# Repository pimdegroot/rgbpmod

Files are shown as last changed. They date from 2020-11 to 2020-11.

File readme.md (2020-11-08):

# RGB Pmod
 ## Introducion
 In this repo you can find the design files and a code example for the rgb matrix pmod I designed. It is based on a 1x1mm RGB led and the GN1640 LED driver.

 The leds used are: https://lcsc.com/product-detail/Light-Emitting-Diodes-LED_Foshan-NationStar-Optoelectronics-FC-B1010RGBT-HG_C158099.html

And the driver is: https://lcsc.com/product-detail/LED-Drivers_GN-GN1640_C265478.html

Note that the TM1640 is pin compatible and an english datasheet can be found for that chip.

When replicating this project it is highly recommended to order a stencil and use solder paste to solder the LEDs

## Usage and Support
Feel free to use the design and code in this repo for your own project. Please credit this repo, or @mifune on twitter if you do.

This is a hobby project that I shared because there has been some interest in it. I will not offer it for sale (though I won't stop you from doing so). Please let me know if there is a file missing in the repo, other than that I won't offer support. I'm already working on the next project.

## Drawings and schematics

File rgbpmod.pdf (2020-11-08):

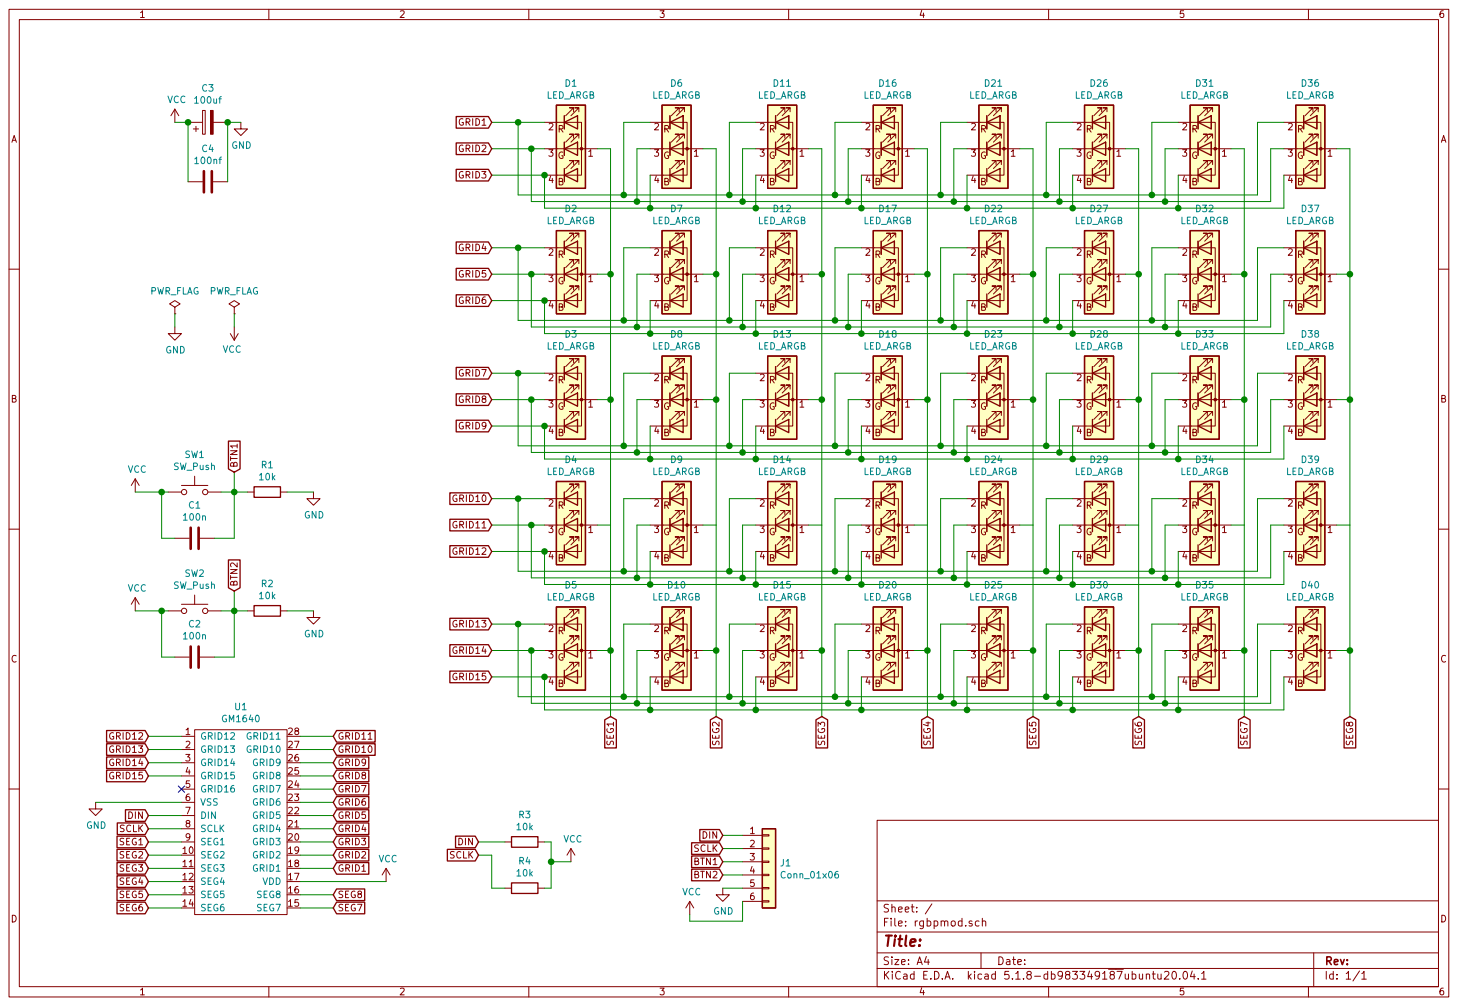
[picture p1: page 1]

File: rgbpmod.sch Sheet: / R4

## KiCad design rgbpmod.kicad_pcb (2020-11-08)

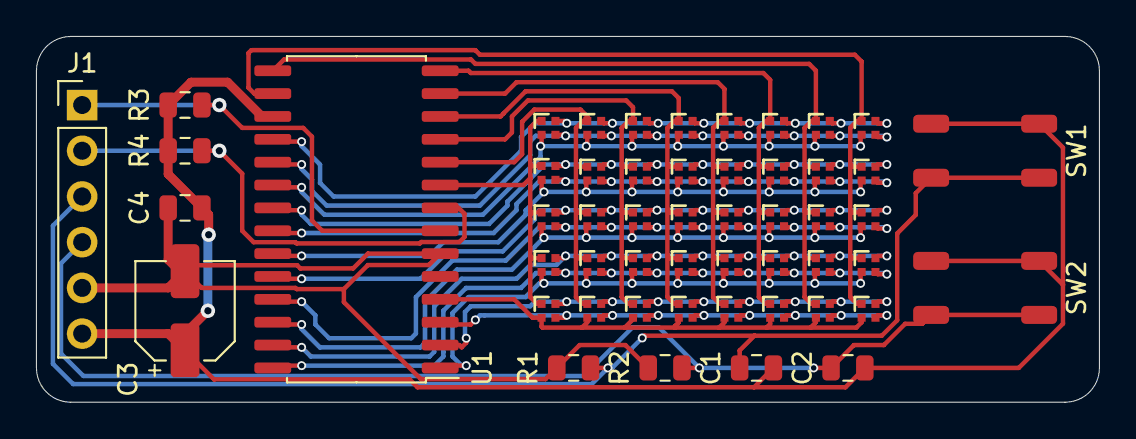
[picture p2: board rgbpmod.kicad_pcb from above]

Board: 2 copper layers, 59.1 x 20.3 mm, 52 parts (0 on the bottom side), 29 nets.

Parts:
C1, C2: 100n; C_0805_2012Metric
C3: 100uf; CP_Elec_5x5.4
C4: 100nf; C_0805_2012Metric
D1, D2, D3, D4, D5, D6, D7, D8, D9, D10, D11, D12, D13, D14, D15, D16, D17, D18, D19, D20, D21, D22, D23, D24, D25, D26, D27, D28, D29, D30, D31, D32, D33, D34, D35, D36, D37, D38, D39, D40: LED_ARGB; 0404_RGB_LED
J1: Conn_01x06; PinHeader_1x06_P2.54mm_Vertical
R1, R2, R3, R4: 10k; R_0805_2012Metric
SW1, SW2: SW_Push; SW
U1: GM1640; SOIC-28W_7.5x17.9mm_P1.27mm

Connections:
BTN1: C1.1, J1.3, R1.2, SW1.2
BTN2: C2.1, J1.4, R2.2, SW2.2
DIN: J1.1, R3.2, U1.7
GND: C3.2, C4.1, J1.5, R1.1, R2.1, U1.6
GRID1: D1.2, D6.2, D11.2, D16.2, D21.2, D26.2, D31.2, D36.2, U1.18
GRID2: D1.3, D6.3, D11.3, D16.3, D21.3, D26.3, D31.3, D36.3, U1.19
GRID3: D1.4, D6.4, D11.4, D16.4, D21.4, D26.4, D31.4, D36.4, U1.20
GRID4: D2.2, D7.2, D12.2, D17.2, D22.2, D27.2, D32.2, D37.2, U1.21
GRID5: D2.3, D7.3, D12.3, D17.3, D22.3, D27.3, D32.3, D37.3, U1.22
GRID6: D2.4, D7.4, D12.4, D17.4, D22.4, D27.4, D32.4, D37.4, U1.23
GRID7: D3.2, D8.2, D13.2, D18.2, D23.2, D28.2, D33.2, D38.2, U1.24
GRID8: D3.3, D8.3, D13.3, D18.3, D23.3, D28.3, D33.3, D38.3, U1.25
GRID9: D3.4, D8.4, D13.4, D18.4, D23.4, D28.4, D33.4, D38.4, U1.26
GRID10: D4.2, D9.2, D14.2, D19.2, D24.2, D29.2, D34.2, D39.2, U1.27
GRID11: D4.3, D9.3, D14.3, D19.3, D24.3, D29.3, D34.3, D39.3, U1.28
GRID12: D4.4, D9.4, D14.4, D19.4, D24.4, D29.4, D34.4, D39.4, U1.1
GRID13: D5.2, D10.2, D15.2, D20.2, D25.2, D30.2, D35.2, D40.2, U1.2
GRID14: D5.3, D10.3, D15.3, D20.3, D25.3, D30.3, D35.3, D40.3, U1.3
GRID15: D5.4, D10.4, D15.4, D20.4, D25.4, D30.4, D35.4, D40.4, U1.4
SCLK: J1.2, R4.2, U1.8
SEG1: D1.1, D2.1, D3.1, D4.1, D5.1, U1.9
SEG2: D6.1, D7.1, D8.1, D9.1, D10.1, U1.10
SEG3: D11.1, D12.1, D13.1, D14.1, D15.1, U1.11
SEG4: D16.1, D17.1, D18.1, D19.1, D20.1, U1.12
SEG5: D21.1, D22.1, D23.1, D24.1, D25.1, U1.13
SEG6: D26.1, D27.1, D28.1, D29.1, D30.1, U1.14
SEG7: D31.1, D32.1, D33.1, D34.1, D35.1, U1.15
SEG8: D36.1, D37.1, D38.1, D39.1, D40.1, U1.16
VCC: C1.2, C2.2, C3.1, C4.2, J1.6, R3.1, R4.1, SW1.1, SW2.1, U1.17

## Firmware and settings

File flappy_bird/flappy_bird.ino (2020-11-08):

#define SDA 2
#define SCL 3

void i2cStart() {
  //generates a high to low SDA transition during SCL high as a start condition
  pinMode(SDA, OUTPUT);
  pinMode(SCL, OUTPUT);
  digitalWrite(SCL, LOW);
  digitalWrite(SDA, HIGH);

  digitalWrite(SCL, HIGH);
  digitalWrite(SDA, LOW);

  digitalWrite(SCL,LOW);
}

void i2cStop() {
  //generates a low to high SDA transition during SCL high as a start condition
  pinMode(SDA, OUTPUT);
  pinMode(SCL, OUTPUT);
  digitalWrite(SCL, LOW);
  digitalWrite(SDA, LOW);

  digitalWrite(SCL, HIGH);
  digitalWrite(SDA, HIGH);

  digitalWrite(SCL,LOW); 
}

byte i2cSend(byte data) {
  //sends data to device and checks for ack
  byte ack = 2;
  pinMode(SDA, OUTPUT);
  pinMode(SCL, OUTPUT);

  digitalWrite(SCL, LOW);
  //send out data
  shiftOut(SDA,SCL,LSBFIRST,data);

  //the GN1640/TN1640 doesn't need an ack

  /*//check for ack
  pinMode(SDA, INPUT);

  digitalWrite(SCL,HIGH);

  ack = digitalRead(SDA);

  digitalWrite(SCL, LOW);
  pinMode(SDA, OUTPUT);*/

  return ack;  
}

void red(){
  //function to create the red game over screen
  i2cStart();
  i2cSend(B11000000); //Address 0
  i2cSend(B11111111);
  i2cSend(B00000000);
  i2cSend(B00000000);
  i2cSend(B11111111);
  i2cSend(B00000000);
  i2cSend(B00000000);
  i2cSend(B11111111);
  i2cSend(B00000000);
  i2cSend(B00000000);
  i2cSend(B11111111);
  i2cSend(B00000000);
  i2cSend(B00000000);
  i2cSend(B11111111);
  i2cSend(B00000000);
  i2cSend(B00000000);
  i2cSend(B01010101);
  i2cStop();
}

byte framebuffer [5][3]; //This array contains the image data, with the first index being the row number, and the second color
byte flappy_height; //Row number of flappy, same as the frame row number
byte pipecounter, pipelocation; //counter for the generation of pipes and the row number of the opening
unsigned int difficulty; //This stores the delay between frames and determines the difficulty

void setup() {

  //filling the initial screen into the framebuffer

  framebuffer[0][0] = B00000001; //Red
  framebuffer[0][1] = B11111111; //Green
  framebuffer[0][2] = B10111110; //Blue

  framebuffer[1][0] = B00000000; //Red
  framebuffer[1][1] = B11111111; //Green
  framebuffer[1][2] = B11111111; //Blue

  framebuffer[2][0] = B00000000; //Red
  framebuffer[2][1] = B11111111; //Green
  framebuffer[2][2] = B11111111; //Blue

  framebuffer[3][0] = B00000000; //Red
  framebuffer[3][1] = B11111111; //Green
  framebuffer[3][2] = B10111111; //Blue

  framebuffer[4][0] = B00000000; //Red
  framebuffer[4][1] = B11111111; //Green
  framebuffer[4][2] = B10111111; //Blue


  i2cStop();
  
  i2cStart();
  i2cSend(B10001001); //Torning the screen on and using the last 3 bits setting the brightness
  i2cStop();

  //setting the defaults for the variables

  flappy_height = 0;
  pipecounter = 2;
  pipelocation = 1;
  difficulty = 800;

  //Pin 16 is the button on the microcontroller board, 22 and 23 the LEDs
  pinMode(16,INPUT);
  pinMode(22,OUTPUT);
  pinMode(23,OUTPUT);

  digitalWrite(22,LOW);
  digitalWrite(23,LOW);
}

void loop() {
  //Sending the frame to the screen.
  i2cStart();
  i2cSend(B11000000); //Address 0
  i2cSend(framebuffer[0][0]);
  i2cSend(framebuffer[0][1]);
  i2cSend(framebuffer[0][2]);
  i2cSend(framebuffer[1][0]);
  i2cSend(framebuffer[1][1]);
  i2cSend(framebuffer[1][2]);
  i2cSend(framebuffer[2][0]);
  i2cSend(framebuffer[2][1]);
  i2cSend(framebuffer[2][2]);
  i2cSend(framebuffer[3][0]);
  i2cSend(framebuffer[3][1]);
  i2cSend(framebuffer[3][2]);
  i2cSend(framebuffer[4][0]);
  i2cSend(framebuffer[4][1]);
  i2cSend(framebuffer[4][2]);

  i2cSend(B11111111); //This row is not connected on the screen
  i2cStop();

  delay(difficulty/2); //Waiting for half the difficulty, to give some time to release the button after the frame change

  flappy_height = flappy_height + 1; //by default flappy drops by one row each frame
  if(digitalRead(16) == true) {
    //if the button is pressed, flappy moves up;
    flappy_height = flappy_height - 2;
  }
  if(flappy_height == 5) {
    //if the bottom is reached, flappy chrashes and game over.
    while(1){
      red();
      digitalWrite(22,HIGH); //the reason why the game is over is shown here
      delay(1000);
    }
  }
  if(flappy_height == 255) {
    //flappy can't exit the screen
    flappy_height = 0;
  }

  delay(difficulty/2); //the other half of the delay is used here

  if(bitRead(framebuffer[flappy_height][2],1) == 0){
    //this part checks for a colision between a tube and flappy, by checking if the pixel ahead contains blue. No air = chrash
    while(1){
      red();
      digitalWrite(23,HIGH);
      delay(1000);
    }
  }

  pipecounter = pipecounter + 1;
  if(pipecounter == 6) {
    //generate a pipe every 5 frames, with a random height;
    pipecounter = 0;
    pipelocation = random(0,4);
    //the delay is decreased every pipe with 10ms
    difficulty = difficulty - 10;
  }

  //the entire frame is shifted by one column
  for(byte y=0;y<5;y++) {
    for(byte c=0;c<3;c++){ 
      //shift entire field
      framebuffer[y][c] = framebuffer[y][c] >> 1;
      if(c==1 || c==2) {
        //Create sky
        framebuffer[y][c] = framebuffer[y][c] | B10000000;
      }

      //regenerate flappy, by adding red and removing blue
      if(y == flappy_height) {
        if(c==0) {
          framebuffer[y][c] = framebuffer[y][c] | B00000001;
        }
        if(c==2) {
          framebuffer[y][c] = framebuffer[y][c] & B11111110;
        }
      }

      //place pipes, by removing blue
      if(pipecounter == 0) {
        if(pipelocation != y && pipelocation+1 != y && c == 2) {
           framebuffer[y][c] = framebuffer[y][c] & B01111111;
        }
      }
    }
  }

  
  
    

}
